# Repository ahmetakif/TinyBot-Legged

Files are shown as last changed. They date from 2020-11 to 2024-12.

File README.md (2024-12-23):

# TinyBot-Legged

This is a 4 legged robot with micro servos. The servos used in this robot are TowerPro SG90 9g Micro servos.



Mechanical design:
- This robot is designed in SolidWorks to be 3D printed with PLA material.
- 23 pieces can be 3D printed to complete this robot.
- All of the parts can be 3D printed with 20% infill.
- Support material can be used if the slicing software suggests. (I am using CURA)
- Parts can be printed with rafts if there is an adhesion issue.

Electronics:
- Raspberry Pi Zero W
- Arduino Nano (Connected to the Raspberry Pi Zero via the USB port.)
- MPU6050 IMU Gyro & Acceleration sensor module
- 12x TowerPro SG90 9g Micro servos
- 2x 3000mAh 3.85v Li-ion smartphone (LG G4) batteries. (One of the batteries power the Arduino and servos and the other one powers the Raspberry Pi.)
- Usb 5v step-up voltage convertor

Software:
- The arduino gets command from the raspberry pi via the usb serial communication port.
- The arduino handles the inverse kinematics calculations.
- Raspberry pi controls the robot with an appropriate gait function and bezier curve.
- Raspberry pi also controls the robot with the help of the IMU sensor data which it receives from the arduino.
- The python script in the raspberry pi also controls the PID balance algorithm.

Note: This project is work in progress. There will be upgrades both with the mechanical design and the software.

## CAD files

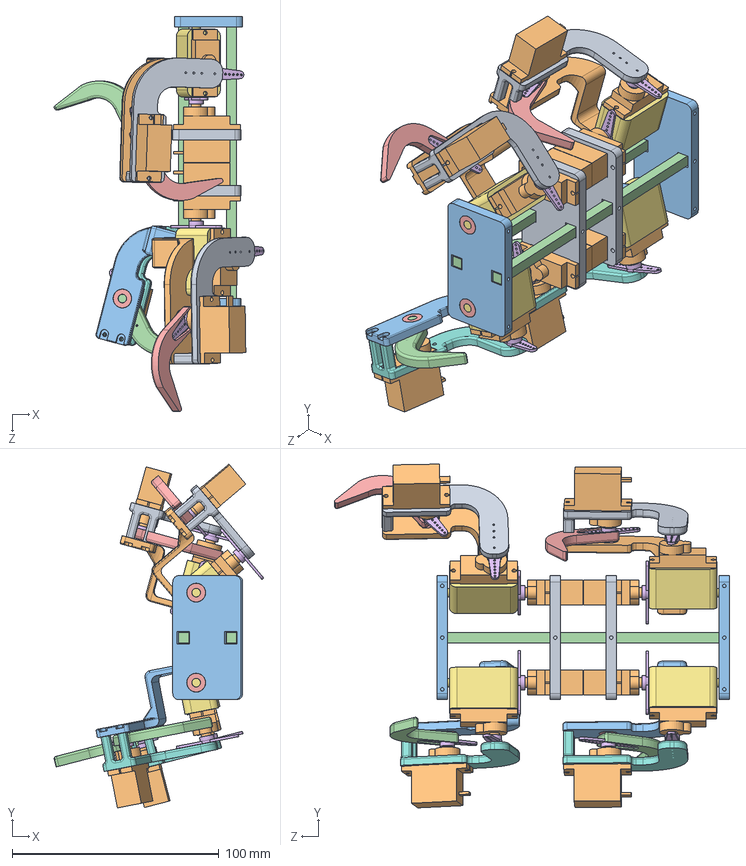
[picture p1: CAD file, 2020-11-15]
SolidWorks/v4_Robot.SLDASM
101.4 x 166.2 x 190.9 mm
Servoholder x 2
v4_Servo x 12
end x 2
Rod x 2
v4_bearing x 12
v4_Servohorn_small x 12
servobox x 4
leg x 2
leg-mirrored x 2
leg-inner-mirrored x 2
leg-inner x 2
foot x 2
foot-mirrored x 2

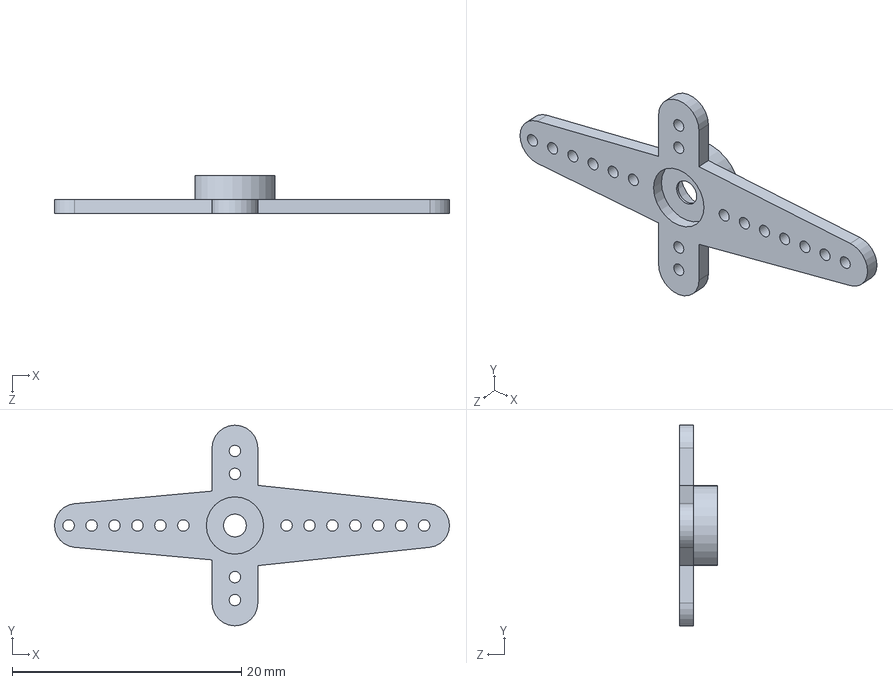
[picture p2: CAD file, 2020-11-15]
SolidWorks/v4_Servohorn.SLDPRT
34.4 x 17.5 x 3.30 mm

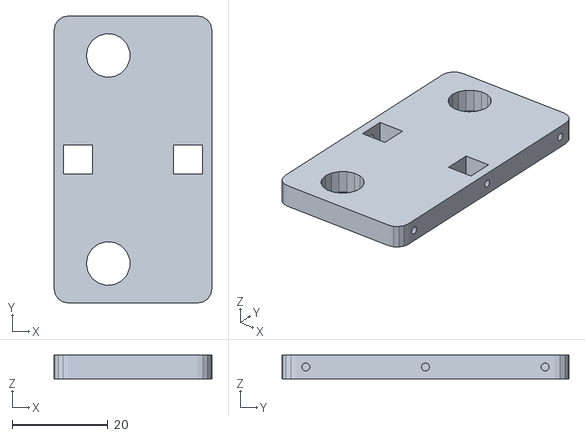
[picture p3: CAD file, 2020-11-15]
STL/end_v2.STL
33.0 x 60.0 x 5.00

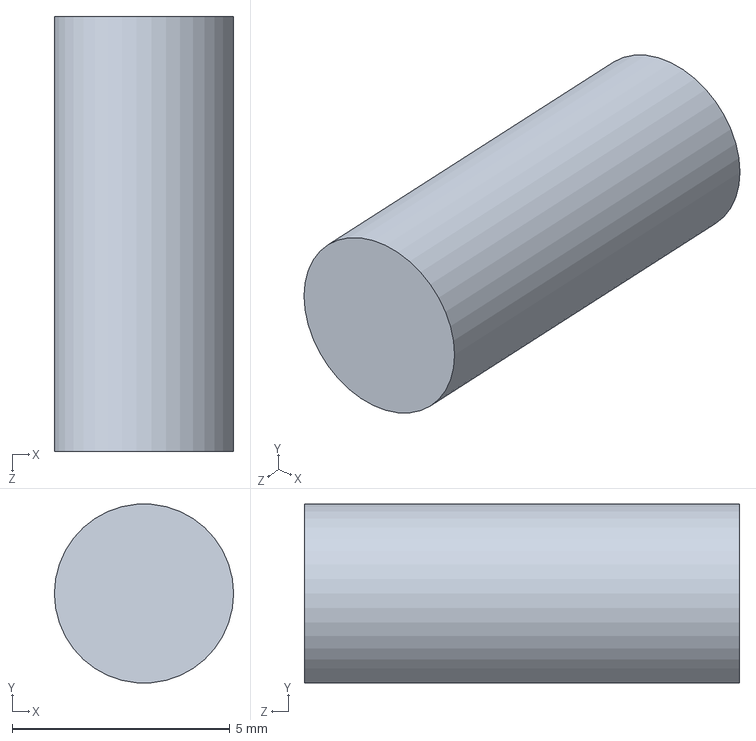
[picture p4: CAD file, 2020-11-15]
SolidWorks/mil.SLDPRT
4.12 x 4.11 x 10.0 mm

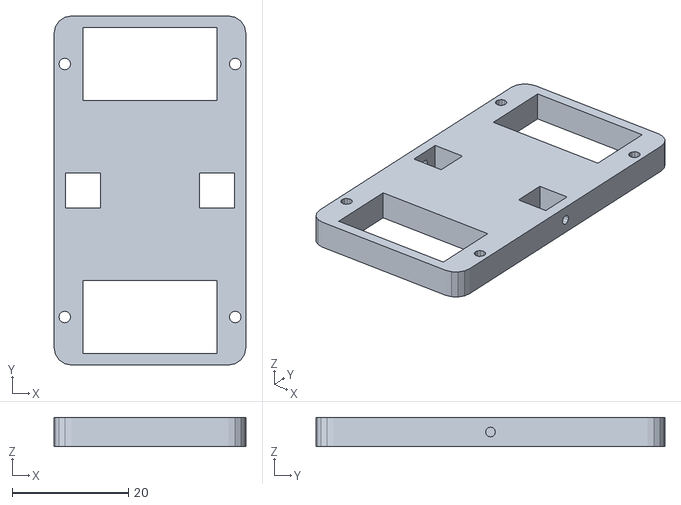
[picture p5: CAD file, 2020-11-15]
STL/Servoholder_v2.STL
33.0 x 60.0 x 5.00

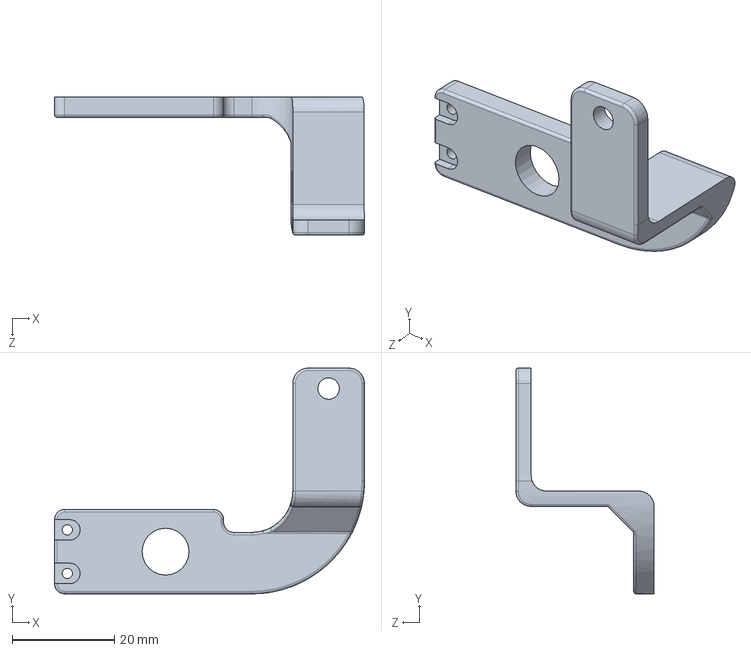
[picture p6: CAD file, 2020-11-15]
SolidWorks/leg-inner-mirrored.SLDPRT
60.5 x 44.1 x 27.0 mm

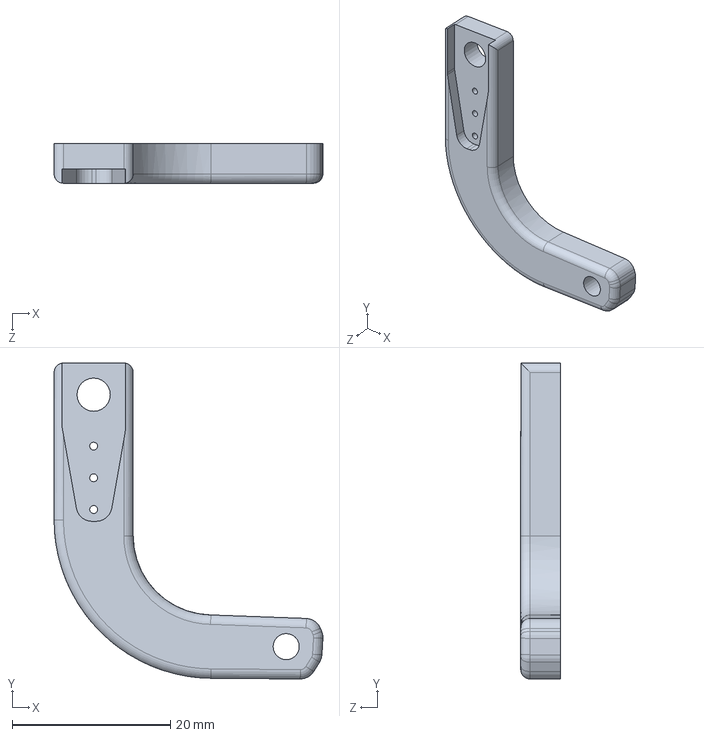
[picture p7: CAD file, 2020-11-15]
SolidWorks/foot-mirrored_v3.SLDPRT
34.0 x 39.9 x 5.00 mm

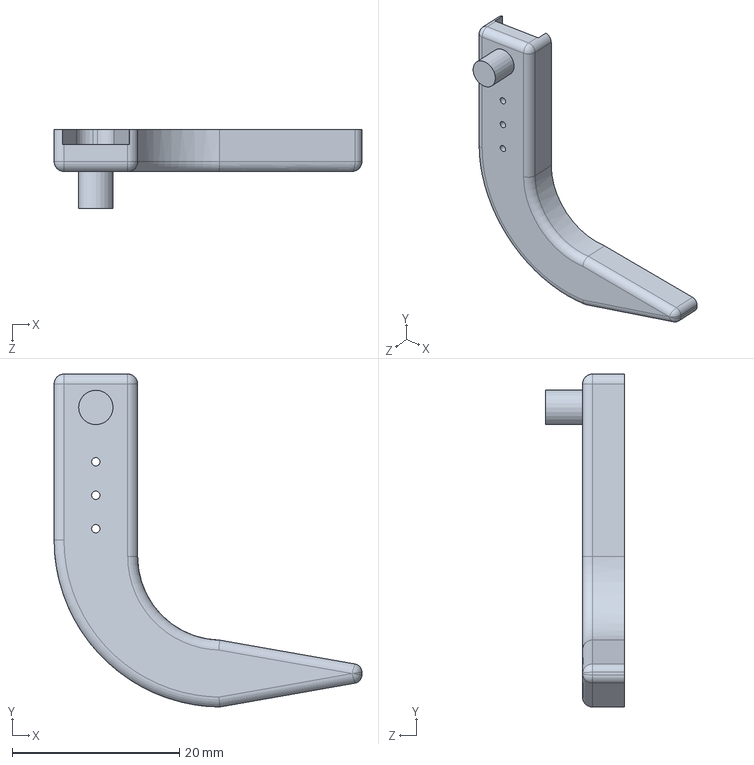
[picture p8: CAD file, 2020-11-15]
SolidWorks/foot.SLDPRT
36.8 x 39.8 x 9.40 mm

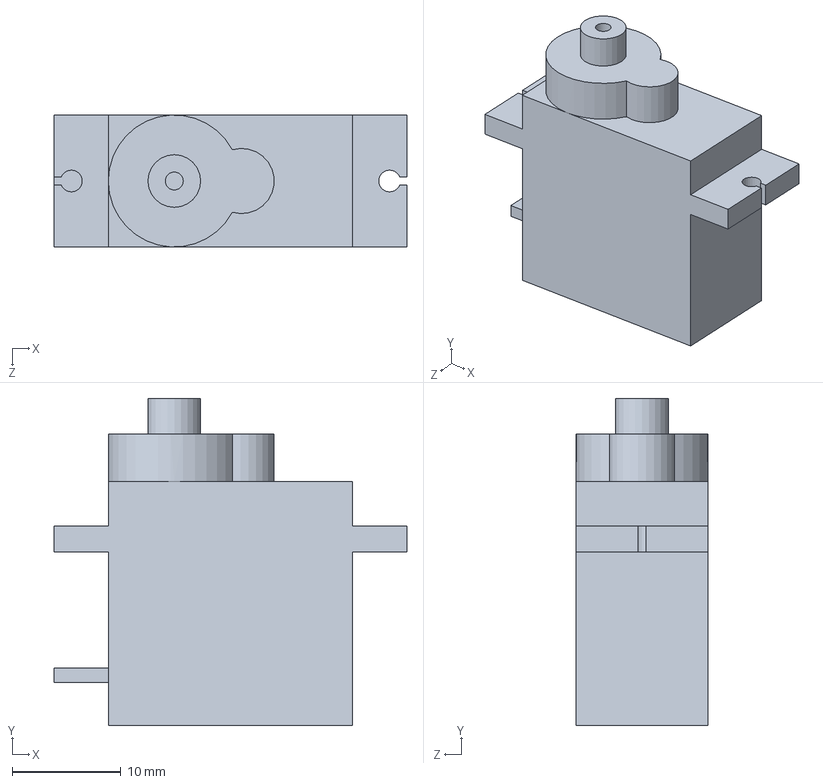
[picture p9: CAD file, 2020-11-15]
SolidWorks/v4_Servo.SLDPRT
32.5 x 30.1 x 12.1 mm

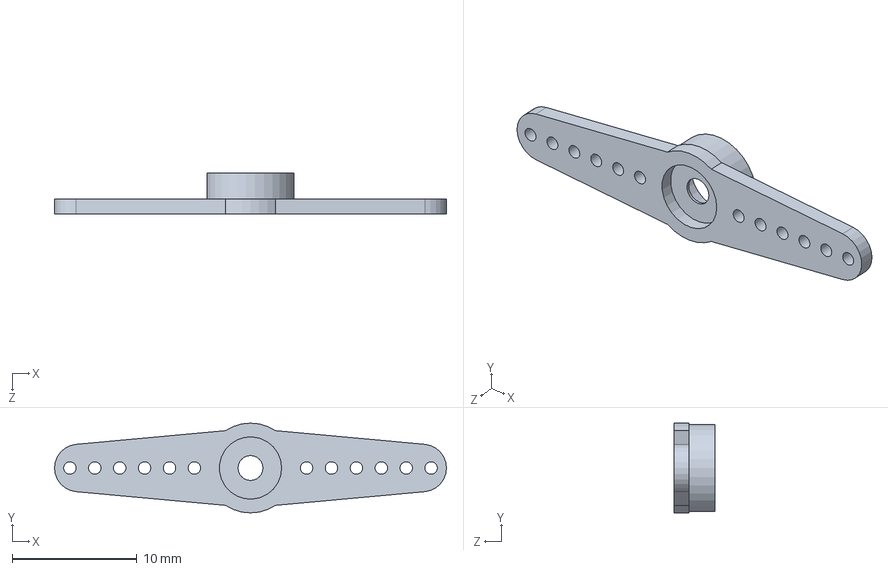
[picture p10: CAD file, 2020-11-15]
SolidWorks/v4_Servohorn_small.SLDPRT
31.5 x 7.21 x 3.30 mm

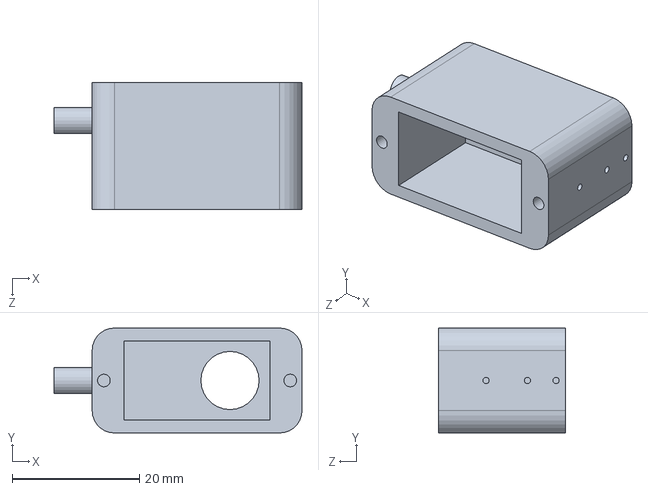
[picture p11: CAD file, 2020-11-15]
SolidWorks/servobox.SLDPRT
39.0 x 16.5 x 20.0 mm

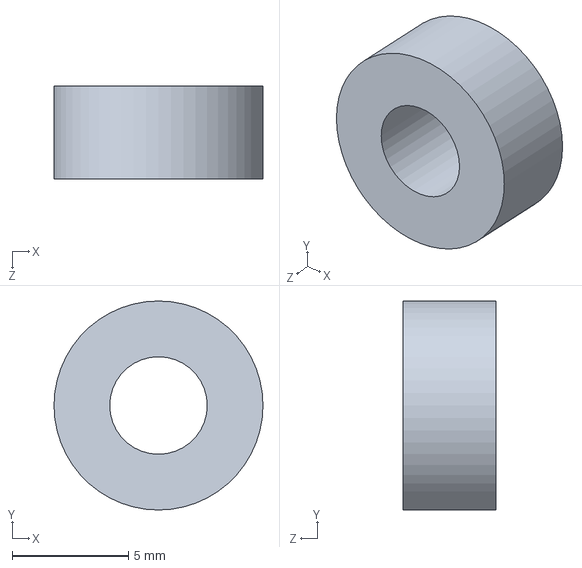
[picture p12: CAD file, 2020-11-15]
SolidWorks/v4_bearing.SLDPRT
9.00 x 9.00 x 4.00 mm

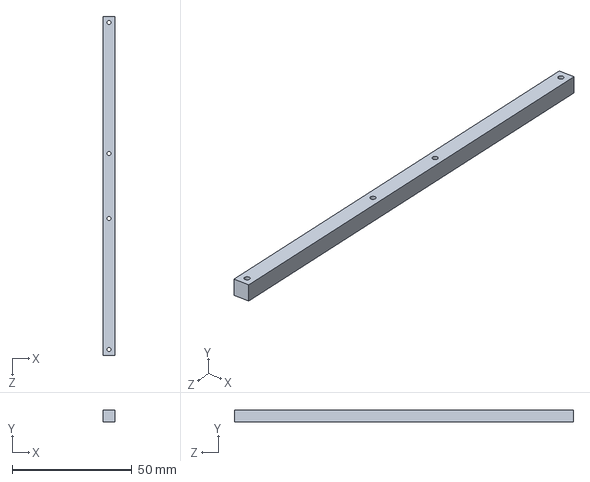
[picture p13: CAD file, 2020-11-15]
SolidWorks/Rod.SLDPRT
5.00 x 5.00 x 141.3 mm

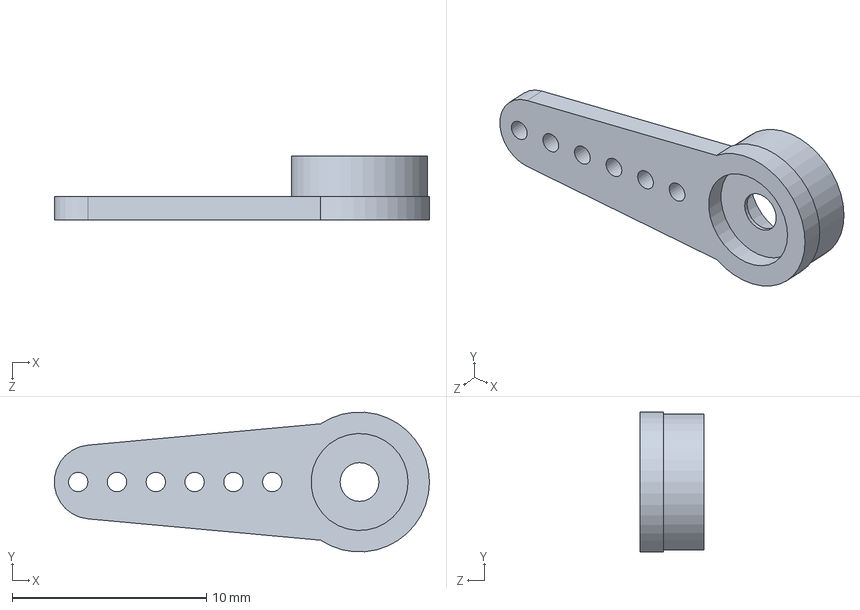
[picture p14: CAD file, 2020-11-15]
SolidWorks/v4_Servohorn_smallest.SLDPRT
19.3 x 7.19 x 3.30 mm

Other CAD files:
SolidWorks/leg-inner.SLDPRT
SolidWorks/Servoholder.SLDPRT
SolidWorks/leg-mirrored.SLDPRT
SolidWorks/leg.SLDPRT
STL/Rod.STL
STL/Servoholder.STL
STL/TopC.STL
STL/end.STL
STL/foot-mirrored.STL
STL/foot-mirrored_v2.STL
STL/foot-mirrored_v3.STL
STL/foot.STL
STL/foot_v2.STL
STL/foot_v3.STL
STL/leg-inner-mirrored.STL
STL/leg-inner.STL
STL/leg-mirrored.STL
STL/leg.STL
STL/mil.STL
STL/servobox.STL
SolidWorks/TopC.SLDPRT
SolidWorks/end.SLDPRT
SolidWorks/foot-mirrored.SLDPRT
SolidWorks/foot-mirrored_v2.SLDPRT
SolidWorks/foot_v2.SLDPRT
SolidWorks/foot_v3.SLDPRT

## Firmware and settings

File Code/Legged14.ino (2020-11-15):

//This is the Arduino Code for the Arduino Nano connected the servo motors and MPU6050
//on the TinyBot Legged Robot
//Authored by Ahmet Akif Kaya | Aug/Sep 2020 
//v.14

//MPU6050 Libraries
#include "I2Cdev.h"
#include "MPU6050.h"
#if I2CDEV_IMPLEMENTATION == I2CDEV_ARDUINO_WIRE
    #include "Wire.h"
#endif

//MPU6050 Init
MPU6050 accelgyro;
int16_t ax, ay, az;
int16_t gx, gy, gz;

float IMUoffsetX = -1600.0;
float IMUoffsetY = -830.0;
const int divideBYX = 375; // Divide the original values to get an angle
const int divideBYY = 265; // Divide the original values to get an angle

//Servos
#include <Servo.h>
Servo fl1;
Servo fl2;
Servo fl3;
Servo fr1;
Servo fr2;
Servo fr3;
Servo bl1;
Servo bl2;
Servo bl3;
Servo br1;
Servo br2;
Servo br3;

//Servo Offsets
const int fl1o = 53;
const int fl2o = 80;
const int fl3o = 96;
const int fr1o = 108;
const int fr2o = 83;
const int fr3o = 94;
const int bl1o = 126;
const int bl2o = 115;
const int bl3o = 83;
const int br1o = 60;
const int br2o = 95;
const int br3o = 94;

//Servo Limit Angles - Limited Mechanically
const int fl1ul = fl1o + 50;  // offset plus  50 limit
const int fl1dl = fl1o - 35;  // offset minus 35 limit
const int fl2ul = fl2o + 38;  // offset plus  38 limit  // INVERSED MOTOR DIRECTION!
const int fl2dl = fl2o - 50;  // offset minus 50 limit  // INVERSED MOTOR DIRECTION!
const int fl3ul = fl3o + 55;  // offset plus  55 limit  // INVERSED MOTOR DIRECTION!
const int fl3dl = fl3o - 75;  // offset minus 75 limit  // INVERSED MOTOR DIRECTION!
//-----------------------------------------
const int fr1ul = fr1o + 35;  // offset plus  35 limit  // INVERSED MOTOR DIRECTION!
const int fr1dl = fr1o - 50;  // offset minus 50 limit  // INVERSED MOTOR DIRECTION!
const int fr2ul = fr2o + 50;  // offset plus  50 limit
const int fr2dl = fr2o - 38;  // offset minus 38 limit
const int fr3ul = fr3o + 75;  // offset plus  75 limit
const int fr3dl = fr3o - 55;  // offset minus 55 limit
//-----------------------------------------
const int bl1ul = bl1o + 35;  // offset plus  35 limit  // INVERSED MOTOR DIRECTION!
const int bl1dl = bl1o - 50;  // offset minus 50 limit  // INVERSED MOTOR DIRECTION!
const int bl2ul = bl2o + 48;  // offset plus  48 limit  // INVERSED MOTOR DIRECTION!
const int bl2dl = bl2o - 50;  // offset minus 50 limit  // INVERSED MOTOR DIRECTION!
const int bl3ul = bl3o + 58;  // offset plus  58 limit  // INVERSED MOTOR DIRECTION!
const int bl3dl = bl3o - 85;  // offset minus 85 limit  // INVERSED MOTOR DIRECTION!
//-----------------------------------------
const int br1ul = br1o + 50;  // offset plus  50 limit
const int br1dl = br1o - 35;  // offset minus 35 limit
const int br2ul = br2o + 50;  // offset plus  50 limit
const int br2dl = br2o - 48;  // offset minus 48 limit
const int br3ul = br3o + 85;  // offset plus  85 limit
const int br3dl = br3o - 58;  // offset minus 58 limit
//-----------------------------------------

// Servo Position Values without the Offsets
int fl1p=0,fl2p=0,fl3p=0,fr1p=0,fr2p=0,fr3p=0,bl1p=0,bl2p=0,bl3p=0,br1p=0,br2p=0,br3p=0; 

//Robot Properties
//---------------- General and for H(Z) axis / up and down movement
const int legfootlen = 45; //In milimeters // Both for leg and foot
const float standardH = 63.63; // Height of the robot in default position
float alphaA = 45.0; //Alpha angle in degrees as default position
float betaA = 90.0; //Beta angle in degrees as default position
float alphaR = (alphaA*PI)/180; // Conversion from degrees to radians
float betaR = (betaA*PI)/180;
//---------------- For X axis / Back and forth movement
float thetaA = 0;
float thetaR = (thetaA*PI)/180;
float h2 = 63.63;
//---------------- For Y axis / Right and left movement
float legYoffset = 20; //This is in milimeters // Will change for different robot designs
float phiR = atan(legYoffset/standardH);
float phiA = (phiR*180)/PI;
float tR = atan(standardH/legYoffset);
float tA = (tR*180)/PI;
float tphiA = (phiA + tA - 90);
float h3 = 63.63;
//---------------- Final alphaA angle, betaA angle, and tphiA angle calculations and conversions
int finalalphaA = (int)(-(alphaA-45));
int finalbetaA = (int)(2*betaA-90);
int finaltphiA = (int)(tphiA);

//////////INVERSE KINEMATICS/////////////////////////////////////////////
//Location Coordinate Properties for Each Leg - In Milimeters
float flH = 63.63;  //Robot up and down (Or Z axis, whatever you call it :))
float flX = 0;      //Robot back and forth
float flY = 0;      //Robot right and left
//----------------------------------------
float frH = 63.63;  //Robot up and down
float frX = 0;      //Robot back and forth
float frY = 0;      //Robot right and left
//----------------------------------------
float blH = 63.63;  //Robot up and down
float blX = 0;      //Robot back and forth
float blY = 0;      //Robot right and left
//----------------------------------------
float brH = 63.63;  //Robot up and down
float brX = 0;      //Robot back and forth
float brY = 0;      //Robot right and left
//----------------------------------------

//Location Coordinate Properties for Each Leg - In Milimeters ////// ROTATIONAL
float rflH = 63.63;  //Robot up and down (Or Z axis, whatever you call it :))
float rflX = 0;      //Robot back and forth
float rflY = 0;      //Robot right and left
//----------------------------------------
float rfrH = 63.63;  //Robot up and down
float rfrX = 0;      //Robot back and forth
float rfrY = 0;      //Robot right and left
//----------------------------------------
float rblH = 63.63;  //Robot up and down
float rblX = 0;      //Robot back and forth
float rblY = 0;      //Robot right and left
//----------------------------------------
float rbrH = 63.63;  //Robot up and down
float rbrX = 0;      //Robot back and forth
float rbrY = 0;      //Robot right and left
//----------------------------------------

//Location Coordinate Properties for Each Leg - In Milimeters ////// ROTATIONAL YAW
float ryflH = 63.63;  //Robot up and down (Or Z axis, whatever you call it :))
float ryflX = 0;      //Robot back and forth
float ryflY = 0;      //Robot right and left
//----------------------------------------
float ryfrH = 63.63;  //Robot up and down
float ryfrX = 0;      //Robot back and forth
float ryfrY = 0;      //Robot right and left
//----------------------------------------
float ryblH = 63.63;  //Robot up and down
float ryblX = 0;      //Robot back and forth
float ryblY = 0;      //Robot right and left
//----------------------------------------
float rybrH = 63.63;  //Robot up and down
float rybrX = 0;      //Robot back and forth
float rybrY = 0;      //Robot right and left
//----------------------------------------

//Location Coordinate Properties for Each Leg - In Milimeters ////// ROTATIONAL PITCH
float rpflH = 63.63;  //Robot up and down (Or Z axis, whatever you call it :))
float rpflX = 0;      //Robot back and forth
float rpflY = 0;      //Robot right and left
//----------------------------------------
float rpfrH = 63.63;  //Robot up and down
float rpfrX = 0;      //Robot back and forth
float rpfrY = 0;      //Robot right and left
//----------------------------------------
float rpblH = 63.63;  //Robot up and down
float rpblX = 0;      //Robot back and forth
float rpblY = 0;      //Robot right and left
//----------------------------------------
float rpbrH = 63.63;  //Robot up and down
float rpbrX = 0;      //Robot back and forth
float rpbrY = 0;      //Robot right and left
//----------------------------------------

//////////ROBOT ROTATION/////////////////////////////////////////////
//Robot Properties
const float rx = 42.5;
const float ry = 41;
const float rhip = sqrt(sq(rx)+sq(ry));
//----------------
float pA = 0;
float rA = 0;
float yA = 0;
float pR = (pA*PI)/180; 
float rR = (rA*PI)/180; 
float yR = (yA*PI)/180; 
//----------------
float tiR = atan(rx/standardH);
float tiA = (tiR*180)/PI; // tiA means the tip angle of the leg
float tiA2 = 90 - tiA;
float fA = 90 - (pA/2) - tiA;
float fR = (fA*PI)/180; 
float fA2 = 180 - 2*tiA - fA;
float fR2 = (fA2*PI)/180;
//----------------
float frontH = standardH;
float rearH = standardH;
//----------------

void setup() {
  //Normal setup
  Serial.begin(9600);
  Serial.setTimeout(5);
  //Welcome message to the raspberry 
  //(Essentially all the messages are sent to the python script on raspberry pi of TinyBot Legged)
  Serial.println("Hello from the arduino nano on the TinyBot Legged.");
  //Attach the servos
  fl1.attach(8);
  fl2.attach(11);
  fl3.attach(10);
  fr1.attach(4);
  fr2.attach(2);
  fr3.attach(7);
  bl1.attach(12);
  bl2.attach(9);
  bl3.attach(5);
  br1.attach(3);
  br2.attach(6);
  br3.attach(13);
  //Moving Servos to offset
  fl1.write(fl1o);
  fl2.write(fl2o);
  fl3.write(fl3o);
  fr1.write(fr1o);
  fr2.write(fr2o);
  fr3.write(fr3o);
  bl1.write(bl1o);
  bl2.write(bl2o);
  bl3.write(bl3o);
  br1.write(br1o);
  br2.write(br2o);
  br3.write(br3o);
  //MPOU6050 Setup
  #if I2CDEV_IMPLEMENTATION == I2CDEV_ARDUINO_WIRE
    Wire.begin();
  #elif I2CDEV_IMPLEMENTATION == I2CDEV_BUILTIN_FASTWIRE
    Fastwire::setup(400, true);
  #endif
  Serial.println("Initializing I2C devices...");
  accelgyro.initialize();
  Serial.println("Testing device connections...");
  Serial.println(accelgyro.testConnection() ? "MPU6050 connection successful" : "MPU6050 connection failed");
}

void loop() {
  if (Serial.available() > 0) {
    String data = Serial.readStringUntil("\n");
    String command = data.substring(0,1);
    int value = 0;
    int leg = 5; //FL:1, FR:2, BL:3, BR:4, ALL:5
    if (command == "_" or command == "=" or command == "&" or command == "?" or command == "!" or command == ";"){
      String legstr = data.substring(1,2);
      String valuestr = data.substring(2);
      leg = legstr.toInt();
      value = valuestr.toInt();
    }
    //----------------------
    //----------------------
    //----------------------
    //----------------------
    if (command == "_"){
      // Elevate axis
      if (leg == 1){
        flH = -value;
      }
      else if (leg == 2){
        frH = -value;
      }
      else if (leg == 3){
        blH = -value;        
      }
      else if (leg == 4){
        brH = -value;
      }
      else{
        flH = value;
        frH = value;
        blH = value;
        brH = value;
      }
      Serial.println((frontH+rearH)/2);
      kinematics("fl",flH+standardH,flX,flY,0);
      kinematics("fr",frH+standardH,frX,frY,0);
      kinematics("bl",blH+standardH,blX,blY,0);
      kinematics("br",brH+standardH,brX,brY,0);
    }
    else if (command == "="){
      //Back and forth axis
      if (leg == 1){
        flX = -value;
      }
      else if (leg == 2){
        frX = -value;
      }
      else if (leg == 3){
        blX = -value;        
      }
      else if (leg == 4){
        brX = -value;
      }
      else{
        flX = value;
        frX = value;
        blX = value;
        brX = value;
      }
      Serial.println(value);
      kinematics("fl",flH+standardH,flX,flY,0);
      kinematics("fr",frH+standardH,frX,frY,0);
      kinematics("bl",blH+standardH,blX,blY,0);
      kinematics("br",brH+standardH,brX,brY,0);
    }
    else if (command == "&"){
      // Right and left axis
      if (leg == 1){
        flY = -value;
      }
      else if (leg == 2){
        frY = value;
      }
      else if (leg == 3){
        blY = -value;        
      }
      else if (leg == 4){
        brY = value;
      }
      else{
        flY = value;
        frY = -value;
        blY = value;
        brY = -value;
      }
      Serial.println(value);
      kinematics("fl",flH+standardH,flX,flY,0);
      kinematics("fr",frH+standardH,frX,frY,0);
      kinematics("bl",blH+standardH,blX,blY,0);
      kinematics("br",brH+standardH,brX,brY,0);
    }
    else if (command == "?"){
      // Pitch axis
      pA = value;
      Serial.println(pA);
      robotrotation((frontH+rearH)/2,pA,rA,yA);
    }
    else if (command == "!"){
      // Roll axis
      rA = value;
      Serial.println(rA);
      robotrotation((frontH+rearH)/2,pA,rA,yA);
    }
    else if (command == ";"){
      // Yaw axis
      yA = value;
      Serial.println(yA);
      robotrotation((frontH+rearH)/2,pA,rA,yA);
    }
    //----------------------
    //----------------------
    //----------------------
    //----------------------
    else if (command == "2") {
      fl1p = fl1p + 1;
      Serial.println(fl1p);
    }
    else if (command == "w") {
      fl1p = fl1p - 1;
      Serial.println(fl1p);
    }
    else if (command == "q") {
      fl2p = fl2p + 1;
      Serial.println(fl2p);
    }
    else if (command == "e") {
      fl2p = fl2p - 1;
      Serial.println(fl2p);
    }
    else if (command == "1") {
      fl3p = fl3p + 1;
      Serial.println(fl3p);
    }
    else if (command == "3") {
      fl3p = fl3p - 1;
      Serial.println(fl3p);
    }
    //----------------------
    else if (command == "5") {
      fr1p = fr1p + 1;
      Serial.println(fr1p);
    }
    else if (command == "t") {
      fr1p = fr1p - 1;
      Serial.println(fr1p);
    }
    else if (command == "r") {
      fr2p = fr2p + 1;
      Serial.println(fr2p);
    }
    else if (command == "y") {
      fr2p = fr2p - 1;
      Serial.println(fr2p);
    }
    else if (command == "4") {
      fr3p = fr3p + 1;
      Serial.println(fr3p);
    }
    else if (command == "6") {
      fr3p = fr3p - 1;
      Serial.println(fr3p);
    }
    //----------------------
    else if (command == "s") {
      bl1p = bl1p + 1;
      Serial.println(bl1p);
    }
    else if (command == "x") {
      bl1p = bl1p - 1;
      Serial.println(bl1p);
    }
    else if (command == "z") {
      bl2p = bl2p + 1;
      Serial.println(bl2p);
    }
    else if (command == "c") {
      bl2p = bl2p - 1;
      Serial.println(bl2p);
    }
    else if (command == "a") {
      bl3p = bl3p + 1;
      Serial.println(bl3p);
    }
    else if (command == "d") {
      bl3p = bl3p - 1;
      Serial.println(bl3p);
    }
    //----------------------
    else if (command == "g") {
      br1p = br1p + 1;
      Serial.println(br1p);
    }
    else if (command == "b") {
      br1p = br1p - 1;
      Serial.println(br1p);
    }
    else if (command == "v") {
      br2p = br2p + 1;
      Serial.println(br2p);
    }
    else if (command == "n") {
      br2p = br2p - 1;
      Serial.println(br2p);
    }
    else if (command == "f") {
      br3p = br3p + 1;
      Serial.println(br3p);
    }
    else if (command == "h") {
      br3p = br3p - 1;
      Serial.println(br3p);
    }
    //----------------------
    //----------------------
    else if (command == "7") {
      resetdefpos();
    }
    //---------------------- TRANSLATION
    //----------------------
    else if (command == "+"){
      flH = flH + 1;
      frH = frH + 1;
      blH = blH + 1;
      brH = brH + 1;
      Serial.println((frontH+rearH)/2);
      kinematics("fl",flH,flX,flY,0);
      kinematics("fr",frH,frX,frY,0);
      kinematics("bl",blH,blX,blY,0);
      kinematics("br",brH,brX,brY,0);
    }
    else if (command == "-"){
      flH = flH - 1;
      frH = frH - 1;
      blH = blH - 1;
      brH = brH - 1;
      Serial.println((frontH+rearH)/2);
      kinematics("fl",flH,flX,flY,0);
      kinematics("fr",frH,frX,frY,0);
      kinematics("bl",blH,blX,blY,0);
      kinematics("br",brH,brX,brY,0);
    }
    //----------------------  
    else if (command == "*"){
      flX = flX + 1;
      frX = frX + 1;
      blX = blX + 1;
      brX = brX + 1;
      Serial.println(flX);
      kinematics("fl",flH,flX,flY,0);
      kinematics("fr",frH,frX,frY,0);
      kinematics("bl",blH,blX,blY,0);
      kinematics("br",brH,brX,brY,0);
    }
    else if (command == "/"){
      flX = flX - 1;
      frX = frX - 1;
      blX = blX - 1;
      brX = brX - 1;
      Serial.println(flX);
      kinematics("fl",flH,flX,flY,0);
      kinematics("fr",frH,frX,frY,0);
      kinematics("bl",blH,blX,blY,0);
      kinematics("br",brH,brX,brY,0);
    }
    //----------------------
    else if (command == "9"){
      flY = flY + 1;
      frY = frY - 1;
      blY = blY + 1;
      brY = brY - 1;
      Serial.println(flY);
      kinematics("fl",flH,flX,flY,0);
      kinematics("fr",frH,frX,frY,0);
      kinematics("bl",blH,blX,blY,0);
      kinematics("br",brH,brX,brY,0);
    }
    else if (command == "8"){
      flY = flY - 1;
      frY = frY + 1;
      blY = blY - 1;
      brY = brY + 1;
      Serial.println(flY);
      kinematics("fl",flH,flX,flY,0);
      kinematics("fr",frH,frX,frY,0);
      kinematics("bl",blH,blX,blY,0);
      kinematics("br",brH,brX,brY,0);
    }
    //---------------------- ROTATION
    //----------------------
    else if (command == "j"){
      pA = pA + 1;
      Serial.println(pA);
      robotrotation((frontH+rearH)/2,pA,rA,yA);
    }
    else if (command == "k"){
      pA = pA - 1;
      Serial.println(pA);
      robotrotation((frontH+rearH)/2,pA,rA,yA);
    }
    //----------------------
    else if (command == "o"){
      rA = rA + 1;
      Serial.println(rA);
      robotrotation((frontH+rearH)/2,pA,rA,yA);
    }
    else if (command == "p"){
      rA = rA - 1;
      Serial.println(rA);
      robotrotation((frontH+rearH)/2,pA,rA,yA);
    }
    //----------------------
    else if (command == "."){
      yA = yA + 1;
      Serial.println(yA);
      robotrotation((frontH+rearH)/2,pA,rA,yA);
    }
    else if (command == ","){
      yA = yA - 1;
      Serial.println(yA);
      robotrotation((frontH+rearH)/2,pA,rA,yA);
    }
    //----------------------
    //----------------------
    else if (command == "<"){
      //IMU data is requested for READ
      accelgyro.getMotion6(&ax, &ay, &az, &gx, &gy, &gz);
      Serial.print("a/g:\t");
      Serial.print((ax + IMUoffsetX)/divideBYX); Serial.print("\t");
      Serial.print((ay + IMUoffsetY)/divideBYY); Serial.print("\t");
      Serial.print(az); Serial.print("\t");
      Serial.print(gx); Serial.print("\t");
      Serial.print(gy); Serial.print("\t");
      Serial.println(gz);
    }
    else if (command == ">"){
      //IMU data is requested for AUTO
      accelgyro.getMotion6(&ax, &ay, &az, &gx, &gy, &gz);
      Serial.println(String((ax + IMUoffsetX)/divideBYX) + ":" + String((ay + IMUoffsetY)/divideBYY));
    }
  }
  moveservo("fl1");
  moveservo("fl2");
  moveservo("fl3");
  moveservo("fr1");
  moveservo("fr2");
  moveservo("fr3");
  moveservo("bl1");
  moveservo("bl2");
  moveservo("bl3");
  moveservo("br1");
  moveservo("br2");
  moveservo("br3");
}
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

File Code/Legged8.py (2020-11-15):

# This is the v8 python code for the TinyBot_Legged controlled by the AKIFBOY via UDP
# Authored by Ahmet Akif Kaya | Aug/Sep 2020

#WELCOME MESSAGES
print(" ")
print("----------------------------")
print("Welcome")
print("This is the v8 code for the TinyBot_Legged controlled by the AKIFBOY via UDP")
print("----------------------------")
print(" ")

#UDP
import socket

UDP_IP = "192.168.1.15" #IP of the robot - same on the robot
UDP_PORT = 5005 # Port - also same on the robot

sock = socket.socket(socket.AF_INET, # Internet
                     socket.SOCK_DGRAM) # UDP
sock.bind((UDP_IP, UDP_PORT))

def helpcommands():
    print(" ")
    print("|-----Meanings of keyboard control commands-----|")
    print("----------------------------")
    print("'akifboy' = Enter the UDP Socket Control Mode, please use the AKIFBOY to control Legged!")
    print("----------------------------")
    print("'keyboardmanualcontrol' or 'k' = Enter the Keyboard Manual Control mode, and use the various keys to control the Legged. If you don't know the control layout, type 'help' after entering this mode.")
    print("----------------------------")
    print("'exit', 'quit', 'escape', 'suspense' = Quits the program")
    print("----------------------------")
    print(" ")

def keyboardmanualcontrolhelp():
    print(" ")
    print("|-----Meanings of keyboard manual control commands-----|")
    print("----------------------------")
    print("'exit', 'quit', 'escape', 'suspense' = Quits the program")
    print("----------------------------")
    print(" ")

#IMPORTMENTS
import serial
#import sys
import time
#import json
import RPi.GPIO as gpio
import random

#ARDUINO SERIAL
a = serial.Serial('/dev/ttyUSB0',9600,timeout=1)
a.flush()

#BALANCE VARIABLES
rollX0 = 0
pitchY1 = 0

#PID FOR BALANCE ROTATE
from simple_pid import PID
rpid = PID(0.1, 0.055, 0.005, setpoint=0)
ppid = PID(0.1, 0.055, 0.005, setpoint=0)
rpid.sample_time = 0
rpid.output_limits = (-10, 10)
ppid.sample_time = 0
ppid.output_limits = (-10, 10)
PIDnomovelimit = 3

#BALANCE TRANSLATE
translatelimit = 15
translatemovelimit = 3
Y0 = 0
X1 = 0

#PID FOR BALANCE TRANSLATE
ypid = PID(0.2, 0.005, 0.0003, setpoint=0)
xpid = PID(0.2, 0.005, 0.0003, setpoint=0)
ypid.sample_time = 0
ypid.output_limits = (-25, 25)
xpid.sample_time = 0
xpid.output_limits = (-25, 25)
PIDnomovelimit = 3

#GAIT PLANNER
#3D POSITIONS FOR EACH LEG
flx = 0
fly = 0
flz = 0
frx = 0
fry = 0
frz = 0
blx = 0
bly = 0
blz = 0
brx = 0
bry = 0
brz = 0
#BEZIER CURVE POINTS
x0 = -27
z0 = 0
x1 = -30
z1 = 20
x2 = 30
z2 = 20
x3 = 27
z3 = 0
x4 = 0
z4 = 0
#GAIT PLANNER POINTS
x5 = (x3-x0)/3
z5 = 0
x6 = (x0-x3)/3
z6 = 0
#BEZIER CURVE T
t = 0
#LOOP DELAY
loopdelay = 0.000001
#LEAN TO SIDES POSITIONS
y0 = 0
y1 = 10
y2 = -10
# Static Gait Planner
controlStaticGaitPlannerFirstTime = 1
controlStaticGaitPlannerGo = 0

def mapp(value, leftMin, leftMax, rightMin, rightMax):
    # Figure out how 'wide' each range is
    leftSpan = leftMax - leftMin
    rightSpan = rightMax - rightMin
    # Convert the left range into a 0-1 range (float)
    valueScaled = float(value - leftMin) / float(leftSpan)
    # Convert the 0-1 range into a value in the right range.
    return rightMin + (valueScaled * rightSpan)

#ARDUINO COMMANDS
def fl1u():
    a.write("2")
    print(a.readline())
def fl1d():
    a.write("w")
    print(a.readline())
def fl2u():
    a.write("q")
    print(a.readline())
def fl2d():
    a.write("e")
    print(a.readline())
def fl3u():
    a.write("1")
    print(a.readline())
def fl3d():
    a.write("3")
    print(a.readline())
#---------------
def fr1u():
    a.write("5")
    print(a.readline())
def fr1d():
    a.write("t")
    print(a.readline())
def fr2u():
    a.write("r")
    print(a.readline())
def fr2d():
    a.write("y")
    print(a.readline())
def fr3u():
    a.write("4")
    print(a.readline())
def fr3d():
    a.write("6")
    print(a.readline())
#---------------
def bl1u():
    a.write("s")
    print(a.readline())
def bl1d():
    a.write("x")
    print(a.readline())
def bl2u():
    a.write("z")
    print(a.readline())
def bl2d():
    a.write("c")
    print(a.readline())
def bl3u():
    a.write("a")
    print(a.readline())
def bl3d():
    a.write("d")
    print(a.readline())
#---------------
def br1u():
    a.write("g")
    print(a.readline())
def br1d():
    a.write("b")
    print(a.readline())
def br2u():
    a.write("v")
    print(a.readline())
def br2d():
    a.write("n")
    print(a.readline())
def br3u():
    a.write("f")
    print(a.readline())
def br3d():
    a.write("h")
    print(a.readline())
#---------------
def resetdefpos():
    a.write("7")
    print(a.readline())
#---------------
def elevateu():
    a.write("+")
    print(a.readline())
def elevated():
    a.write("-")
    print(a.readline())
def backandforthu():
    a.write("*")
    print(a.readline())
def backandforthd():
    a.write("/")
    print(a.readline())
def rightandleftu():
    a.write("9")
    print(a.readline())
def rightandleftd():
    a.write("8")
    print(a.readline())
#---------------
def pitchu():
    a.write("j")
    print(a.readline())
def pitchd():
    a.write("k")
    print(a.readline())
def rollu():
    a.write("o")
    print(a.readline())
def rolld():
    a.write("p")
    print(a.readline())
def yawu():
    a.write(".")
    print(a.readline())
def yawd():
    a.write(",")
    print(a.readline())
#---------------
def elevate(leg,value): #FL:1, FR:2, BL:3, BR:4, ALL:5
    a.write("_" + str(leg) + str(value) + "\n")
    print(a.readline())
def backandforth(leg,value):
    a.write("=" + str(leg) + str(value) + "\n")
    print(a.readline())
def rightandleft(leg,value):
    a.write("&" + str(leg) + str(value) + "\n")
    print(a.readline())
#---------------
def pitch(value):
    a.write("?" + str(5) + str(value) + "\n")
    print(a.readline())
def roll(value):
    a.write("!" + str(5) + str(value) + "\n")
    print(a.readline())
def yaw(value):
    a.write(";" + str(5) + str(value) + "\n")
    print(a.readline())
#---------------
def imudatarequest():
    print(" ")
    print("Requesting the IMU data right now.")
    print(" ")
    a.write("<" + "\n")
    time.sleep(0.1)
    return a.readline()
def imudata():
    a.write(">" + "\n")
    incoming = a.readline()
    angle = incoming.split(":")
    print(angle)
    angle[0] = float(angle[0])
    angle[1] = float(angle[1][:-2])
    return angle
#---------------
#---------------
#---------------
def balancerotate():
    global rollX0
    global pitchY1
    anglen = imudata()
    if anglen[0] > 4:
        rollX0 = rollX0 - 1
    elif anglen[0] < -4:
        rollX0 = rollX0 + 1
    if anglen[1] > 4:
        pitchY1 = pitchY1 - 1
    elif anglen[1] < -4:
        pitchY1 = pitchY1 + 1
    roll(rollX0)
    pitch(pitchY1)
#---------------
def balancerotatePID():
    global rollX0
    global pitchY1
    anglen = imudata()
    if anglen[0] > PIDnomovelimit or anglen[0] < -PIDnomovelimit:
        #PID FOR ROLL
        routput = rpid(anglen[0])
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
